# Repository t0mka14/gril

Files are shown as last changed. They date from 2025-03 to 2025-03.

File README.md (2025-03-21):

# gril
A gril control unit for reflowing pcbs. The project consists of two parts - Micropython code for Rpi Pico and one PCB. \
**PCB**\
Apart from the Pico there is MAX31855 that converts temperature of thermocouple glued to the grill plate and sends it over SPI to PICO. Then there is one mosfet to control external SSR and linear stabilizer as the input voltage is 12V. The whole device is controlled using rotary encoder connected to GPIO pins 19-21. The encoder button goes to 19. The display is any 16x4 I2C LCD.\
**Code**\
The code uses two Asyncio loops, one for controlling temperature and on for displaying stuff. If you want to tune the PID controller, you can change parameters on line 92 in gril.py

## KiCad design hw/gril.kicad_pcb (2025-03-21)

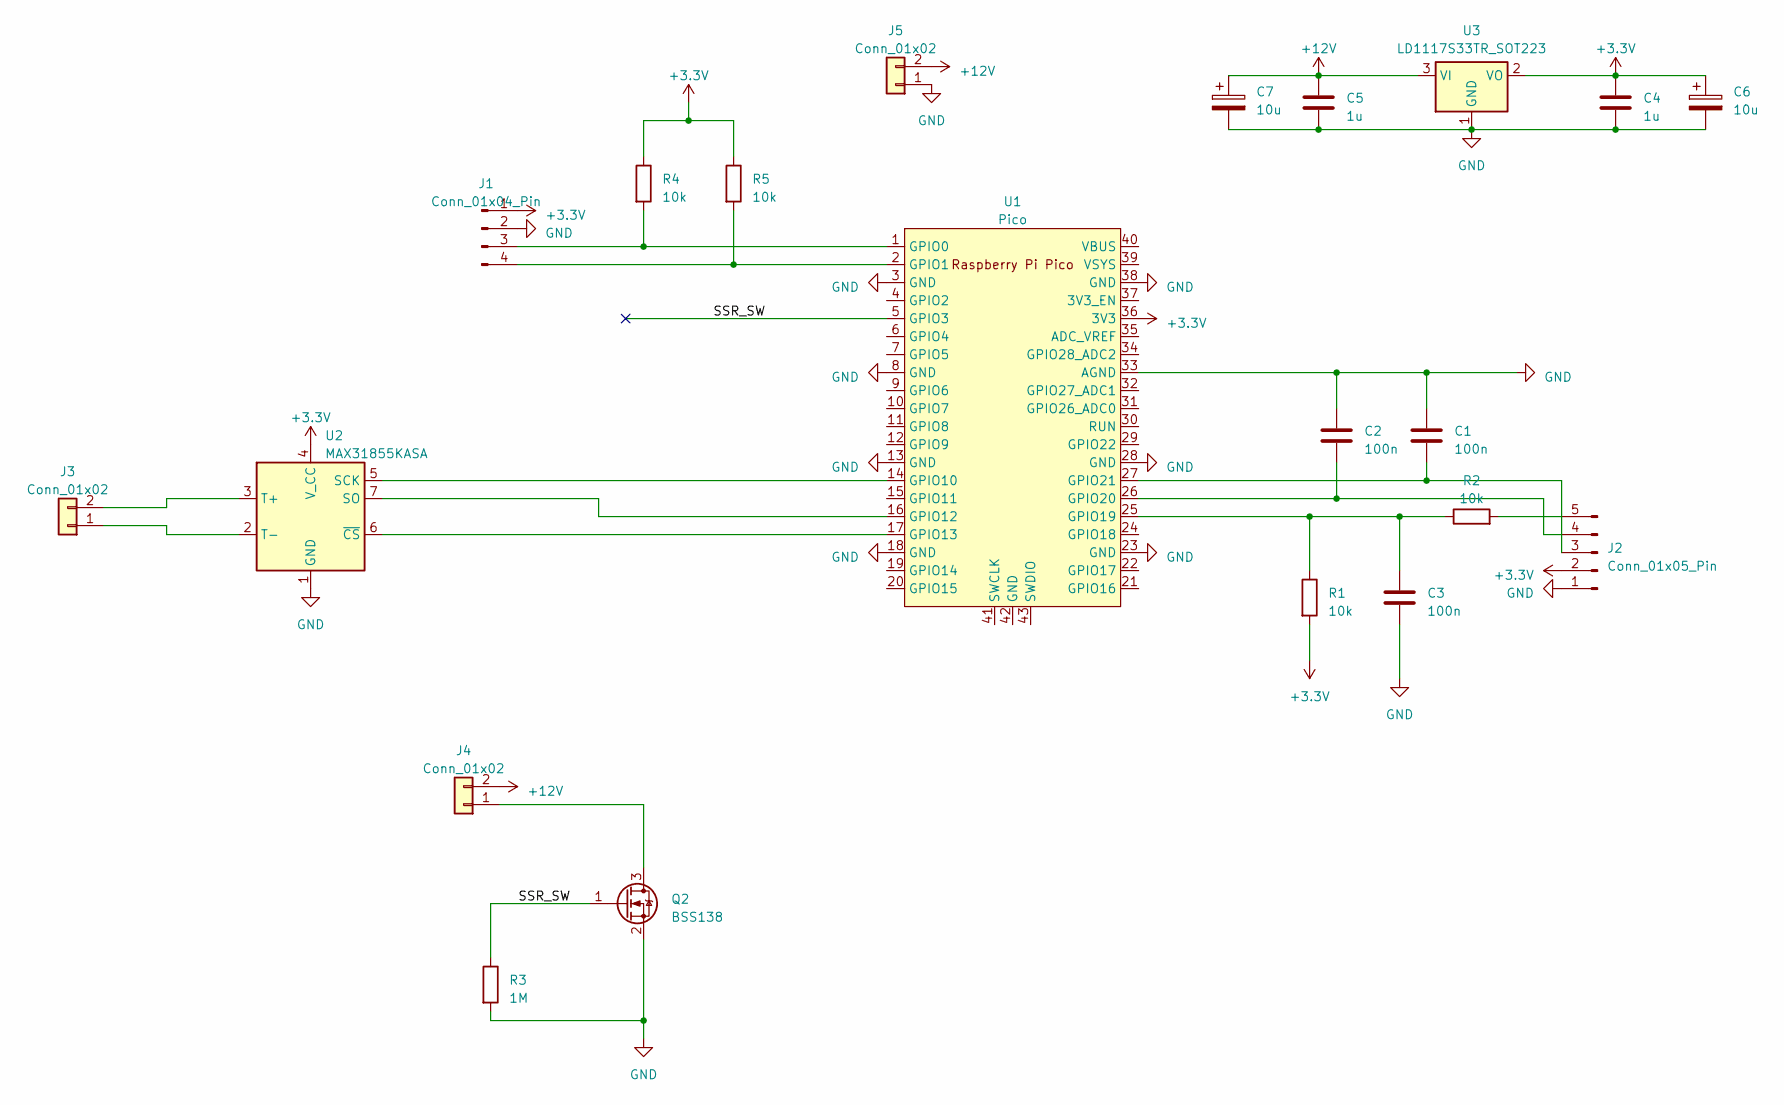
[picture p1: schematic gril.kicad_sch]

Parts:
C1: 100n; NetTie-4_SMD_Pad0.5mm
C2, C3: 100n; C_0805_2012Metric
C4, C5: 1u; C_0805_2012Metric
C6, C7: 10u; CP_Radial_D8.0mm_P3.80mm
J1: Conn_01x04_Pin; PinHeader_1x04_P2.54mm_Vertical
J2: Conn_01x05_Pin; PinHeader_1x05_P2.54mm_Vertical
J3, J4, J5: Conn_01x02; PinHeader_1x02_P2.54mm_Vertical
Q2: BSS138; SOT-23
R1, R2, R4, R5: 10k; R_0805_2012Metric
R3: 1M; R_0805_2012Metric
U1: Pico; RPi_Pico_SMD_TH
U2: MAX31855KASA; SOIC-8_3.9x4.9mm_P1.27mm
U3: LD1117S33TR_SOT223; SOT-223-3_TabPin2

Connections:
+3.3V: C4.1, C6.1, J1.1, J2.2, R1.2, R4.1, R5.1, U1.36 (3V3), U2.4 (V_CC), U3.2 (VO)
+12V: C5.1, C7.1, J4.2, J5.2, U3.3 (VI)
/SSR_SW: Q2.1 (G), R3.1, U1.5 (GPIO3)
GND: C1.2, C2.1, C3.2, C4.2, C5.2, C6.2, C7.2, J1.2, J2.1, J5.1, Q2.2 (S), R3.2, U1.3 (GND), U1.8 (GND), U1.13 (GND), U1.18 (GND), U1.23 (GND), U1.28 (GND), U1.33 (AGND), U1.38 (GND), U2.1 (GND), U3.1 (GND)
unnamed: J1.3, R4.2, U1.1 (GPIO0)
unnamed: J1.4, R5.2, U1.2 (GPIO1)
unnamed: C1.1, J2.3, U1.27 (GPIO21)
unnamed: C2.2, J2.4, U1.26 (GPIO20)
unnamed: J2.5, R2.2
unnamed: J3.1, U2.2 (T-)
unnamed: J3.2, U2.3 (T+)
unnamed: J4.1, Q2.3 (D)
unnamed: U1.14 (GPIO10), U2.5 (SCK)
unnamed: U1.16 (GPIO12), U2.7 (SO)
unnamed: U1.17 (GPIO13), U2.6 (~CS)
unnamed: C3.1, R1.1, R2.1, U1.25 (GPIO19)

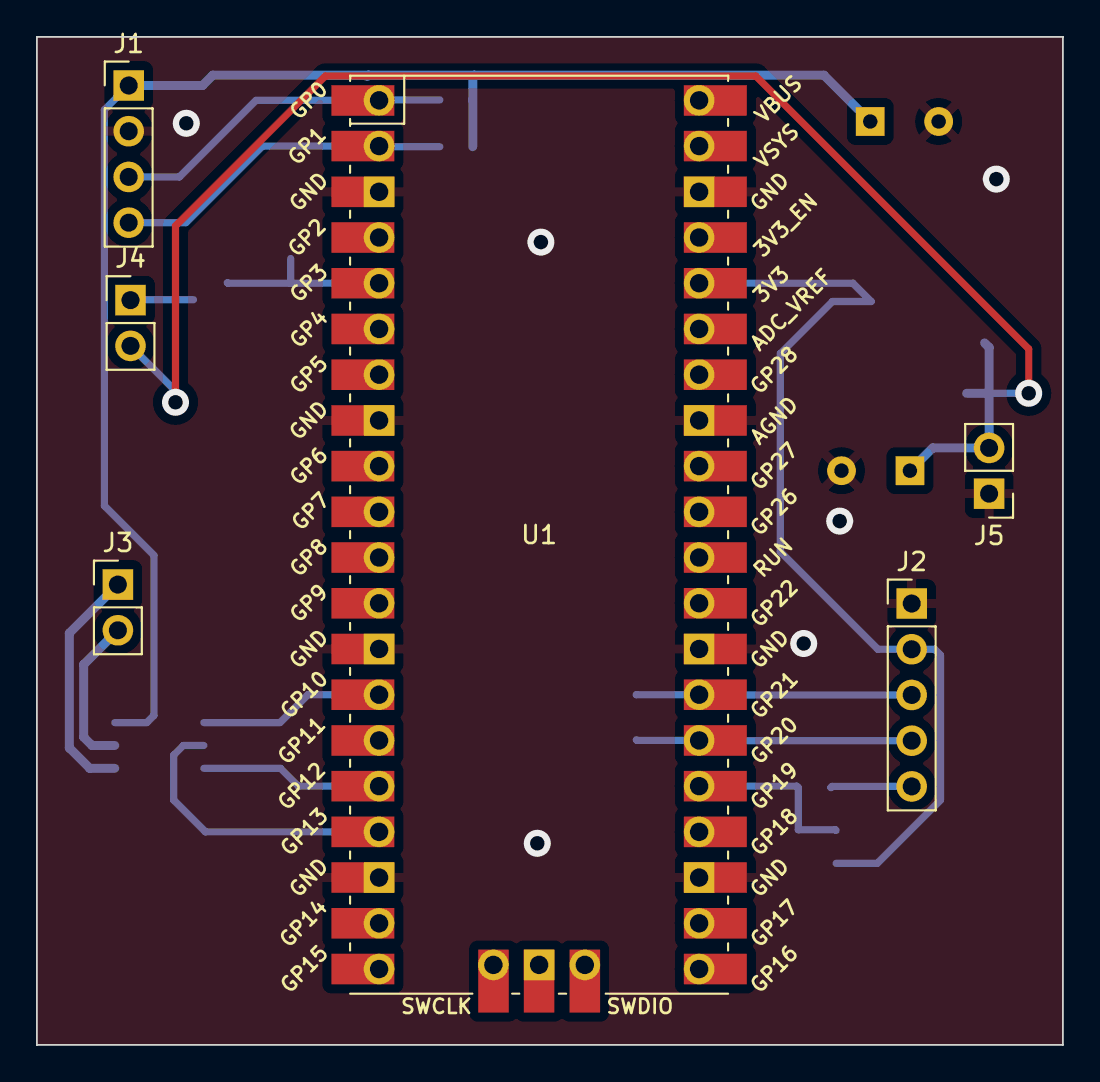
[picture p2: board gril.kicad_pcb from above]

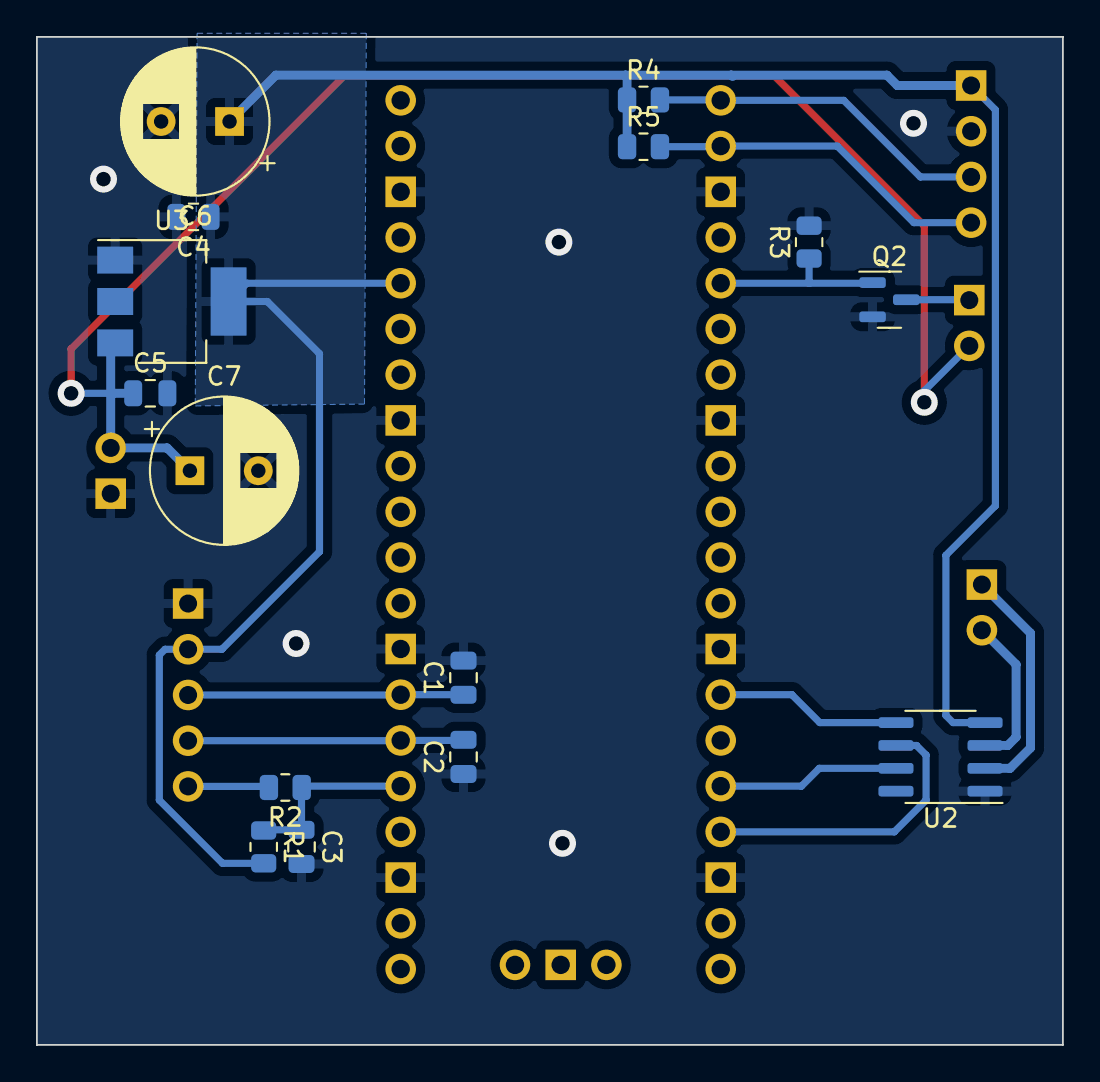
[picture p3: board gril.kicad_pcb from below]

Board: 2 copper layers, 57.0 x 56.0 mm, 21 parts (15 on the bottom side), 16 nets.

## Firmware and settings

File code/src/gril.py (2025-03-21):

from machine import Pin, SPI, I2C
import uasyncio
from lib.regulator import PID
from lib.max31855 import MAX31855
from lib.pico_i2c_lcd import I2cLcd
from src.Display import Display
from src.Profile import Profile
cs = Pin(13, Pin.OUT)
spi = SPI(1, 10_000_000, sck=Pin(10), mosi=Pin(11), miso=Pin(12))
tempSensor = MAX31855(spi, cs)



I2C_ADDR = 0x27
I2C_NUM_ROWS = 4
I2C_NUM_COLS = 20
i2c = I2C(0, scl=Pin(1), sda=Pin(0), freq=400000)
lcd = I2cLcd(i2c, I2C_ADDR, I2C_NUM_ROWS, I2C_NUM_COLS)


beeperPin = Pin(5, Pin.OUT)
encPlus = Pin(21, Pin.IN)
encPlusLastState = 0
encPlusNewState = 0
encMinus = Pin(20, Pin.IN)
encButton = Pin(19, Pin.IN)  # Pressed when low
encValue = 0
buttonPressed = False
setTemp = 0
elapsedTime = 0

relay = Pin(3, Pin.OUT)


profile = None

##############################################
#Rotary encoder methods
def handlePlusIrq(pin: Pin):
    global encPlusNewState
    encPlusNewState = pin.value()
def readTestRotary(pin: Pin):
    global encPlusLastState
    global encValue
    if (pin.value() != encPlusLastState):
        encPlusLastState = pin.value()
        if (pin.value() == 0 and encMinus.value() == 1):
            # turn right
            encValue += 5
        elif (pin.value() == 1 and encMinus.value() == 0):
            # turn right
            encValue += 5
        elif (pin.value() == 1 and encMinus.value() == 1):
            # turn left
            encValue -= 5
        else:
            # turn left
            encValue -= 5
def readButtonRotary(pin :Pin):
    global buttonPressed
    buttonPressed = True

encPlus.irq(handler=readTestRotary)
encButton.irq(handler=readButtonRotary, trigger = Pin.IRQ_FALLING)
def readEncoderValue():
    return encValue
def readSetTemp():
    return setTemp
def readElapsedTime():
    return elapsedTime
def readReflowTime():
    if profile is not None:
        return profile.profile[-1][1]
    else:
        return 0
##########################################################
def readTemperature():
    try:
        return tempSensor.read()
    except Exception as e:
        return e

#callback from display!
def startReflow(type):
    global profile
    profile = Profile(readTemperature,type)
    uasyncio.create_task(tempControl())

##############################################


pid = PID(readTemperature,P=2, I=0.7, D=0.1)

display = Display(lcd,readSetTemp,readTemperature,pid, startReflow, readElapsedTime,readEncoderValue, readReflowTime)

loop = uasyncio.get_event_loop()
###############################################


def tempControl():
    global setTemp
    global elapsedTime
    period = 1
    elapsedTime = 0
    while (profile.profile[-1][1] + 30 > elapsedTime):
            setTemp = profile.calculateTempForTime(elapsedTime)
            onTime = pid.getOnTime(setTemp)
            if onTime == 1:
                relay.value(1)
                await uasyncio.sleep(period)
            elif onTime == 0:
                relay.value(0)
                await uasyncio.sleep(period)
            else:
                relay.value(1)
                await uasyncio.sleep(onTime)
                relay.value(0)
                await uasyncio.sleep(period - onTime)
            ####beep when finished
            if (elapsedTime > profile.profile[-1][1] and elapsedTime < profile.profile[-1][1] + 5):
                beeperPin.value(1)
            else:
                beeperPin.value(0)
            elapsedTime += 1
    relay.value(0)
    display.goToMainMenu()


def displayControl():
  global buttonPressed
  displayClearTimer = 0
  while(True):
    display.show(buttonPressed)
    buttonPressed = False
    displayClearTimer += 200
    if displayClearTimer > 5*60000:
        display.refreshAllPixels()
        displayClearTimer = 0
    await uasyncio.sleep_ms(200)




uasyncio.create_task(displayControl())


# uasyncio.create_task(readRotary())
loop.run_forever()

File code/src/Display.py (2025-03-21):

import gc
import uasyncio

from lib.pico_i2c_lcd import I2cLcd
from lib.regulator import PID
from src.Profile import Profile


class Display:
    def __init__(self, lcd: I2cLcd, setTemp, readTemp, pid: PID, startReflow, elapsedTime, encValue, readReflowTime):
        self.lcd = lcd
        self.setTemp = setTemp
        self.readTemp = readTemp
        self.startReflow = startReflow
        self.encValue = encValue
        self.readReflowTime = readReflowTime
        self.pid = pid
        self.menuX = 0
        self.menuY = 0
        self.sinceLastBlink = 0
        self.cursorOn = False

        self.lastEncValue = 0
        self.wasError = False
        self.currentScreen = "main"
        self.selectedProfile = ""
        self.elapsedTime = elapsedTime

        self.mainMenuConstants()

    # Prints constants for running reflow
    def runningConstDisplay(self):
        self.lcd.clear()
        self.lcd.move_to(0, 0)
        self.lcd.putstr("Actual temp: ")
        self.lcd.move_to(0, 1)
        self.lcd.putstr("Set temp: ")
        self.lcd.move_to(0, 2)
        self.lcd.putstr("D: ")
        self.lcd.move_to(8, 2)
        self.lcd.putstr("Time: ")
        self.lcd.move_to(0, 3)
        self.lcd.putstr("PID: ")

    # Screen to be shown during reflow
    def reflowRunningDisplay(self):
        temp = self.readTemp()
        if type(temp) is not float:
            if not self.wasError: self.lcd.clear()
            self.lcd.move_to(0, 0)
            self.lcd.putstr(str(temp))
            self.wasError = True
            return
        if self.wasError:
            self.lcd.clear()
            self.runningConstDisplay()
            self.wasError = False
        self.lcd.move_to(14, 0)
        self.lcd.putstr(str(temp))
        self.lcd.move_to(10, 1)
        self.lcd.putstr("%.2f" % self.setTemp() + "  ")
        self.lcd.move_to(3, 2)
        self.lcd.putstr("%.2f" % self.pid.d)
        self.lcd.move_to(13, 2)
        self.lcd.putstr(str(self.elapsedTime()))
        self.lcd.putstr("/")
        self.lcd.putstr(str(self.readReflowTime()))
        self.lcd.move_to(5, 3)
        self.lcd.putstr("%.2f" % self.pid.pidValue + "  ")

    def mainMenuConstants(self):
        self.lcd.clear()
        self.lcd.move_to(0, 0)
        self.lcd.putstr("Gril v 1.1")
        self.lcd.move_to(0, 2)
        self.lcd.putstr("Leaded")
        self.lcd.move_to(10, 2)
        self.lcd.putstr("Lead free")
        self.lcd.move_to(0, 3)
        self.lcd.putstr("Gril temp: ")
        self.menuX = 0
        self.menuY = 2
        self.lcd.move_to(self.menuX, self.menuY)

    def mainMenu(self):
        if self.encValue() > self.lastEncValue:
            self.menuX = 10
            self.menuY = 2
            self.lastEncValue = self.encValue()
        elif self.encValue() < self.lastEncValue:
            self.menuX = 0
            self.menuY = 2
            self.lastEncValue = self.encValue()
        self.lcd.move_to(11, 3)
        self.lcd.putstr(str(self.readTemp()))
        self.lcd.move_to(self.menuX, self.menuY)
        if self.sinceLastBlink > 2:
            if self.cursorOn:
                self.lcd.putstr("L")
                self.cursorOn = False
                self.sinceLastBlink = 0
            else:
                self.cursorOn = True
                self.lcd.putAllBlack()
                self.sinceLastBlink = 0

    def confirmMenuConstants(self):
        self.lcd.clear()
        self.lcd.move_to(0, 0)
        if self.selectedProfile == "leaded":
            self.lcd.putstr("Leaded (temp, sec):")
        else:
            self.lcd.putstr("Pbfree (temp, sec):")
        self.lcd.move_to(0, 1)
        profile = Profile(self.readTemp, self.selectedProfile).readProfile()
        self.lcd.putstr(str(profile[0]) + str(profile[1]))
        self.lcd.move_to(0, 2)
        self.lcd.putstr(str(profile[2]) + str(profile[3]))
        self.lcd.move_to(0, 3)
        self.lcd.putstr("Ok")
        self.lcd.move_to(10, 3)
        self.lcd.putstr("Back")
        self.lcd.move_to(0, 3)
        self.menuX = 0
        self.menuY = 3
        gc.collect()

    def confirmMenu(self):
        if self.encValue() > self.lastEncValue:
            self.menuX = 10
            self.menuY = 3
            self.lastEncValue = self.encValue()
            self.lcd.move_to(self.menuX, self.menuY)
        elif self.encValue() < self.lastEncValue:
            self.menuX = 0
            self.menuY = 3
            self.lastEncValue = self.encValue()
            self.lcd.move_to(self.menuX, self.menuY)


    # this is to remove bad pixels which appear after some time
    def refreshAllPixels(self):
        self.lcd.clear()
        if self.currentScreen == "main":
            self.mainMenuConstants()
        elif self.currentScreen == "confirmation":
            self.confirmMenuConstants()
        elif self.currentScreen == "reflow":
            self.runningConstDisplay()

    def goToMainMenu(self):
        self.lcd.clear()
        self.mainMenuConstants()
        self.currentScreen = "main"
    def show(self, click):
        self.sinceLastBlink += 1
        if self.currentScreen == "main":
            if click:
                if self.menuX == 0:
                    self.currentScreen = "confirmation"
                    self.selectedProfile = "leaded"
                    self.confirmMenuConstants()
                    self.lcd.blink_cursor_on()
                elif self.menuX == 10:
                    self.currentScreen = "confirmation"
                    self.selectedProfile = "leadfree"
                    self.confirmMenuConstants()
                    self.lcd.blink_cursor_on()
            else:
                self.mainMenu()
        elif self.currentScreen == "reflow":
            self.reflowRunningDisplay()
        elif self.currentScreen == "confirmation":
            if click:
                if self.menuX == 0:
                    self.currentScreen = "reflow"
                    self.runningConstDisplay()
                    self.lcd.hide_cursor()
                    self.startReflow(self.selectedProfile)
                elif self.menuX == 10:
                    self.currentScreen = "main"
                    self.lcd.hide_cursor()
                    self.mainMenuConstants()
            else:
                self.confirmMenu()
        else:
            self.mainMenu()
